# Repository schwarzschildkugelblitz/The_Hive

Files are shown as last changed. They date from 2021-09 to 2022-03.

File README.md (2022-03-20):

# The Hive 
The Following is Team Placeholders Solution to Flipkart's Grid 3.0

## About Grid 3.0
60ccb1a9ee892_d2c__1920-557_01

GRiD is Flipkart’s Flagship Engineering Campus Challenge which provides you the opportunity to apply your technical knowledge and skills, to compete and complete key challenges.

In its third edition, Flipkart GRiD becomes bigger & better, bringing Live Problem Statements from the world of E-Commerce to the brightest minds of India and lets you put your capabilities to the ultimate test.
## Problem  Statement

### Relay race - 4 Robots

1. Each robot has a package on top
2. Start positions are S1, S2, S3 & S4
3. Bot from S1 is expected to go to D1, Bot from S2 is expected to go to D2 and so on...
4. On start - Bot in the S1 location is expected to go to D1
5. On reaching D1 it should drop the item beyond the wall
6. Once the bot comes back to S1 (Completely inside S1 square), only then Bot from S2 can start
7. Race is over when S4 robot comes back to its square after dropping the parcel
No touching of the robots hardware/software is allowed once the race starts - Completely autonomous robots
Overall Arena size is 5 x 10ft

● Each block is 6x6in

● The grid is 1 cm tape / marking

● The brown line next to D1, D2, D3 & D4 is a 1-inch height wall

### Judging Criteria for Round I

Top 100 teams to finish the relay race (shortest time) - make it to Round II

### Deliverables for Round I
1. Pictures of Robots
2. Time taken to complete the relay race
3. Uninterrupted Video of the Relay Race - with Timer overlayed to indicate start and end of race - This
can be shot with a handheld or phone camera
4. Uninterrupted Video of Live Image Processing - with Timer overlayed to show how robots are being
tracked in real-time

## About The Team 
Untitled design

The Team consisted of the following members 
1. Harshit Batra 
2. Tanmay Vadhera
3. Mudit Aggarwal
4. Rohan Deswal
5. Drishti Adlakha 
6. Arjun Narula 
7. Harshit Kapoor
8. Mukul Gupta 
9. Vikas Poddar 
10. Soham

## Achitectrue
architecure drawio (6)

### Queen Tracking System 
### Transmission System
### Worker bee 
WhatsApp Image 2021-09-06 at 4 18 25 PM

## Mechanical

## Electronics 
### Power system 
the worker bee is power by powerfull 7.2 V 2500 mah li-ion Battery

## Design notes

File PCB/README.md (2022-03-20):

# PCB for Bot 

## Iteration 1 

Designed By Team Placeholders and Manufactured By PCB Powers 

### Dimensions

### Parts 

1. Arduino nano 
2. L293D
3. Power circuit 
4. NRF24 

### Funionality 

1. Driving bot's N20 Motor 
2. Driving bot's Servo Motor  
3. Receiving Data from Central Tracking system 

### Schmatic Diagram 
151336828-df838c24-ffac-4909-9ef3-fa408727c776

### 3D view 
pcb_flip

## Iteration 2

Designed By Team Placeholders and Manufactured at CEDT lab,NSUT

### What's new 

1. Added boost cicuit 
2. Changed dimensions 

### Parts 

1. Arduino nano 
2. L293D
3. Power circuit 
4. NRF24 

### Funionality 
1. Driving bot's N20 Motor 
2. Driving bot's Servo Motor  
3. Receiving Data from Central Tracking system 

### Schmatic Diagram 
pcb_flip (1)

### 3D view 
pcb_flip

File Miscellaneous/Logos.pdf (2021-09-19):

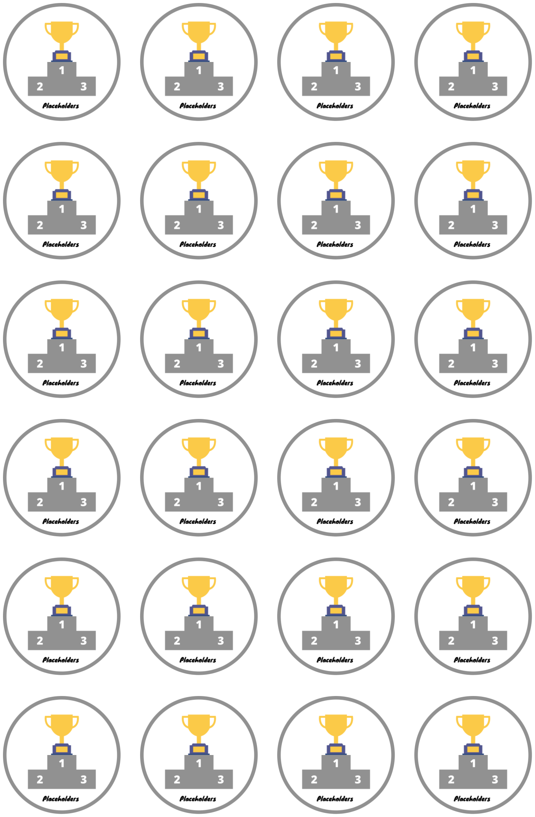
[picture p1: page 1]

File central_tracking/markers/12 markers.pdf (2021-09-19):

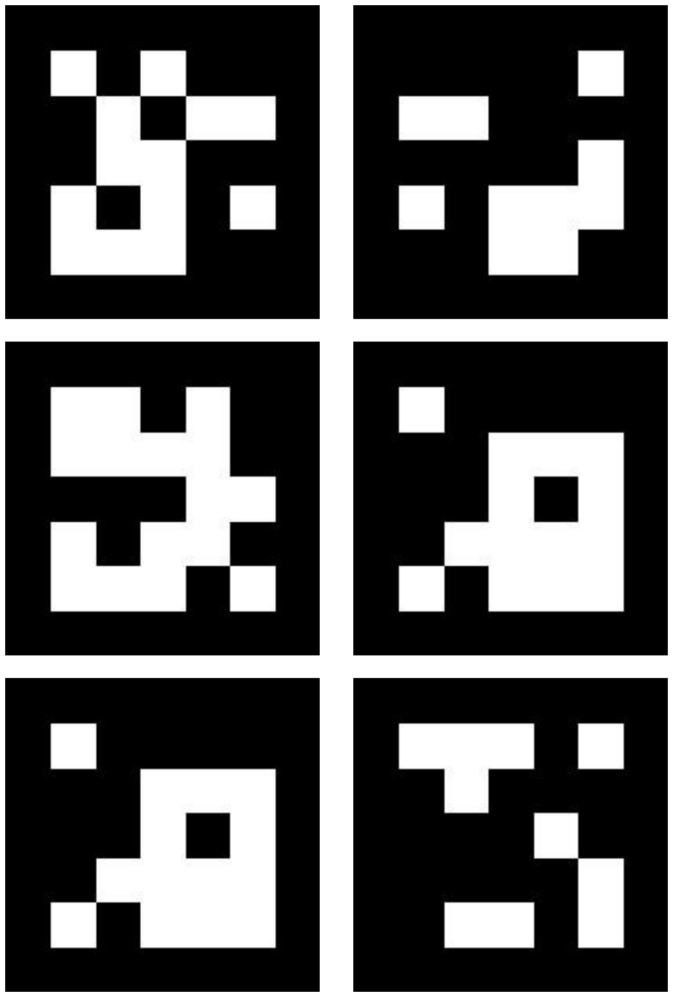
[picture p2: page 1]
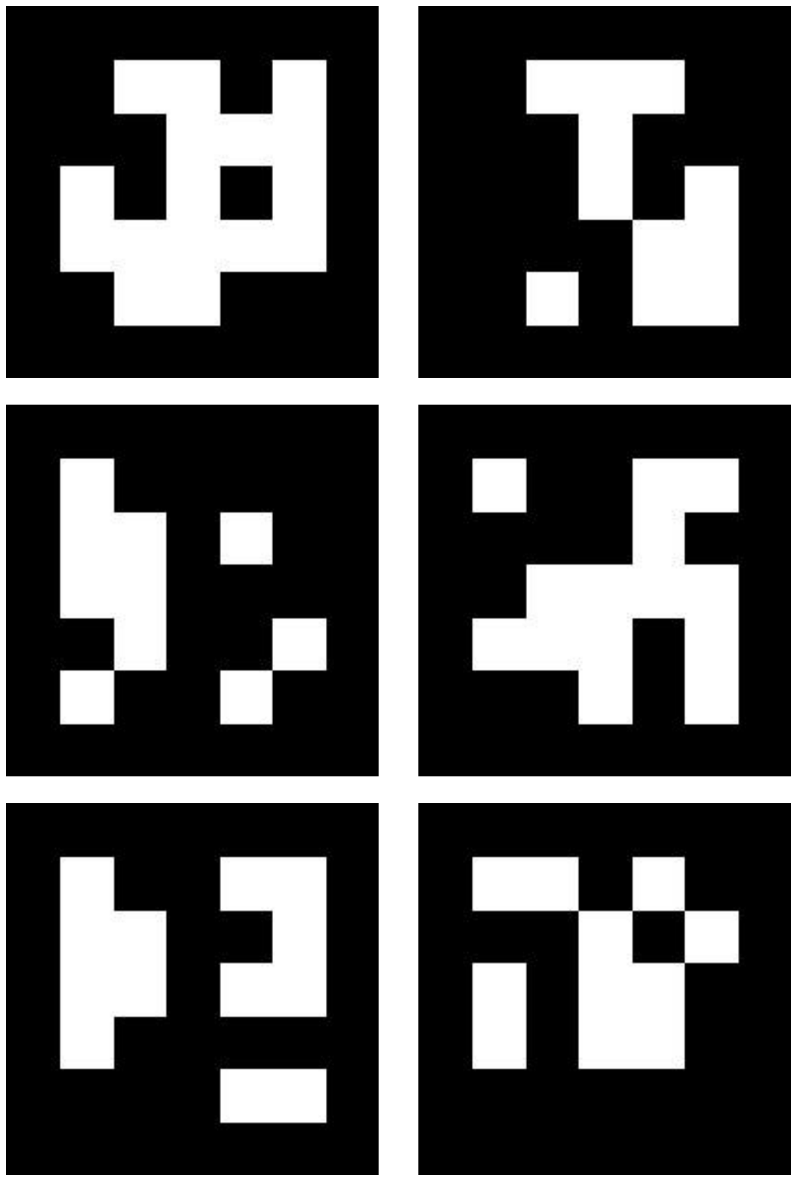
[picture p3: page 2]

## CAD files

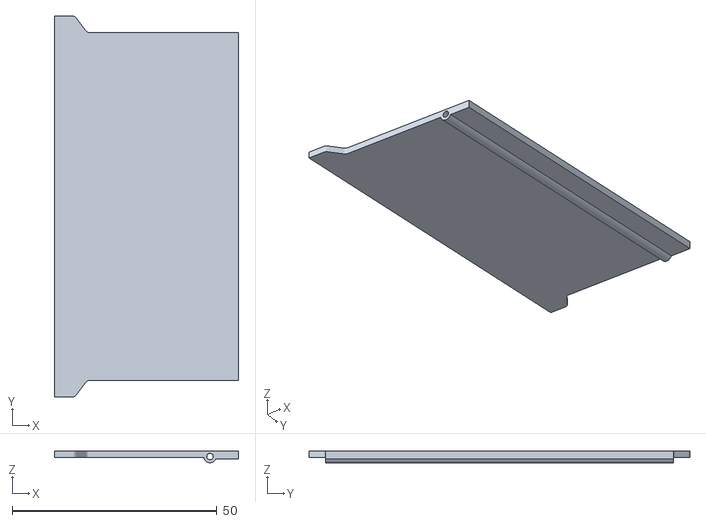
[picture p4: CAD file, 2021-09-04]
CAD_Model/flipper_plate_send.stl
45.0 x 93.0 x 2.84

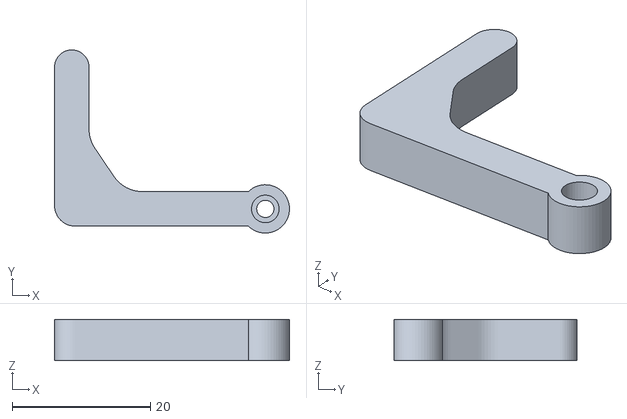
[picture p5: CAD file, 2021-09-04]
CAD_Model/L arm fin.stl
34.0 x 26.5 x 6.00

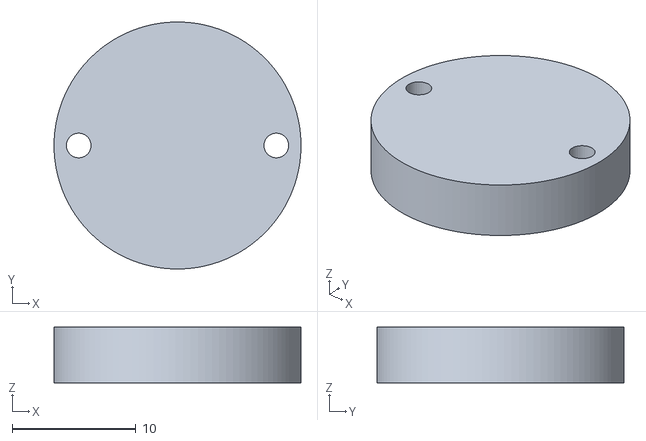
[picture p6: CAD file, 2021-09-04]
CAD_Model/caster spacer v1.stl
20.0 x 20.0 x 4.50

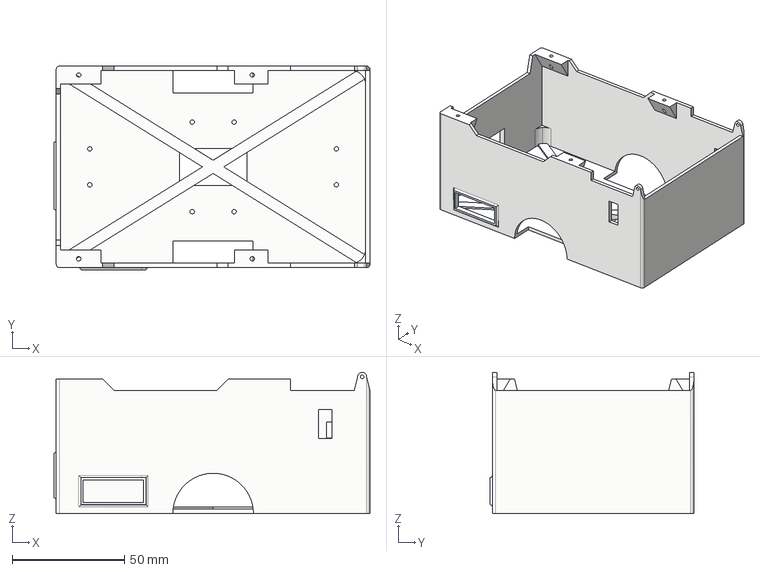
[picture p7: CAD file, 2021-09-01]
CAD_Model/ROBOT_W_changes v3.step
141.0 x 91.0 x 63.0 mm

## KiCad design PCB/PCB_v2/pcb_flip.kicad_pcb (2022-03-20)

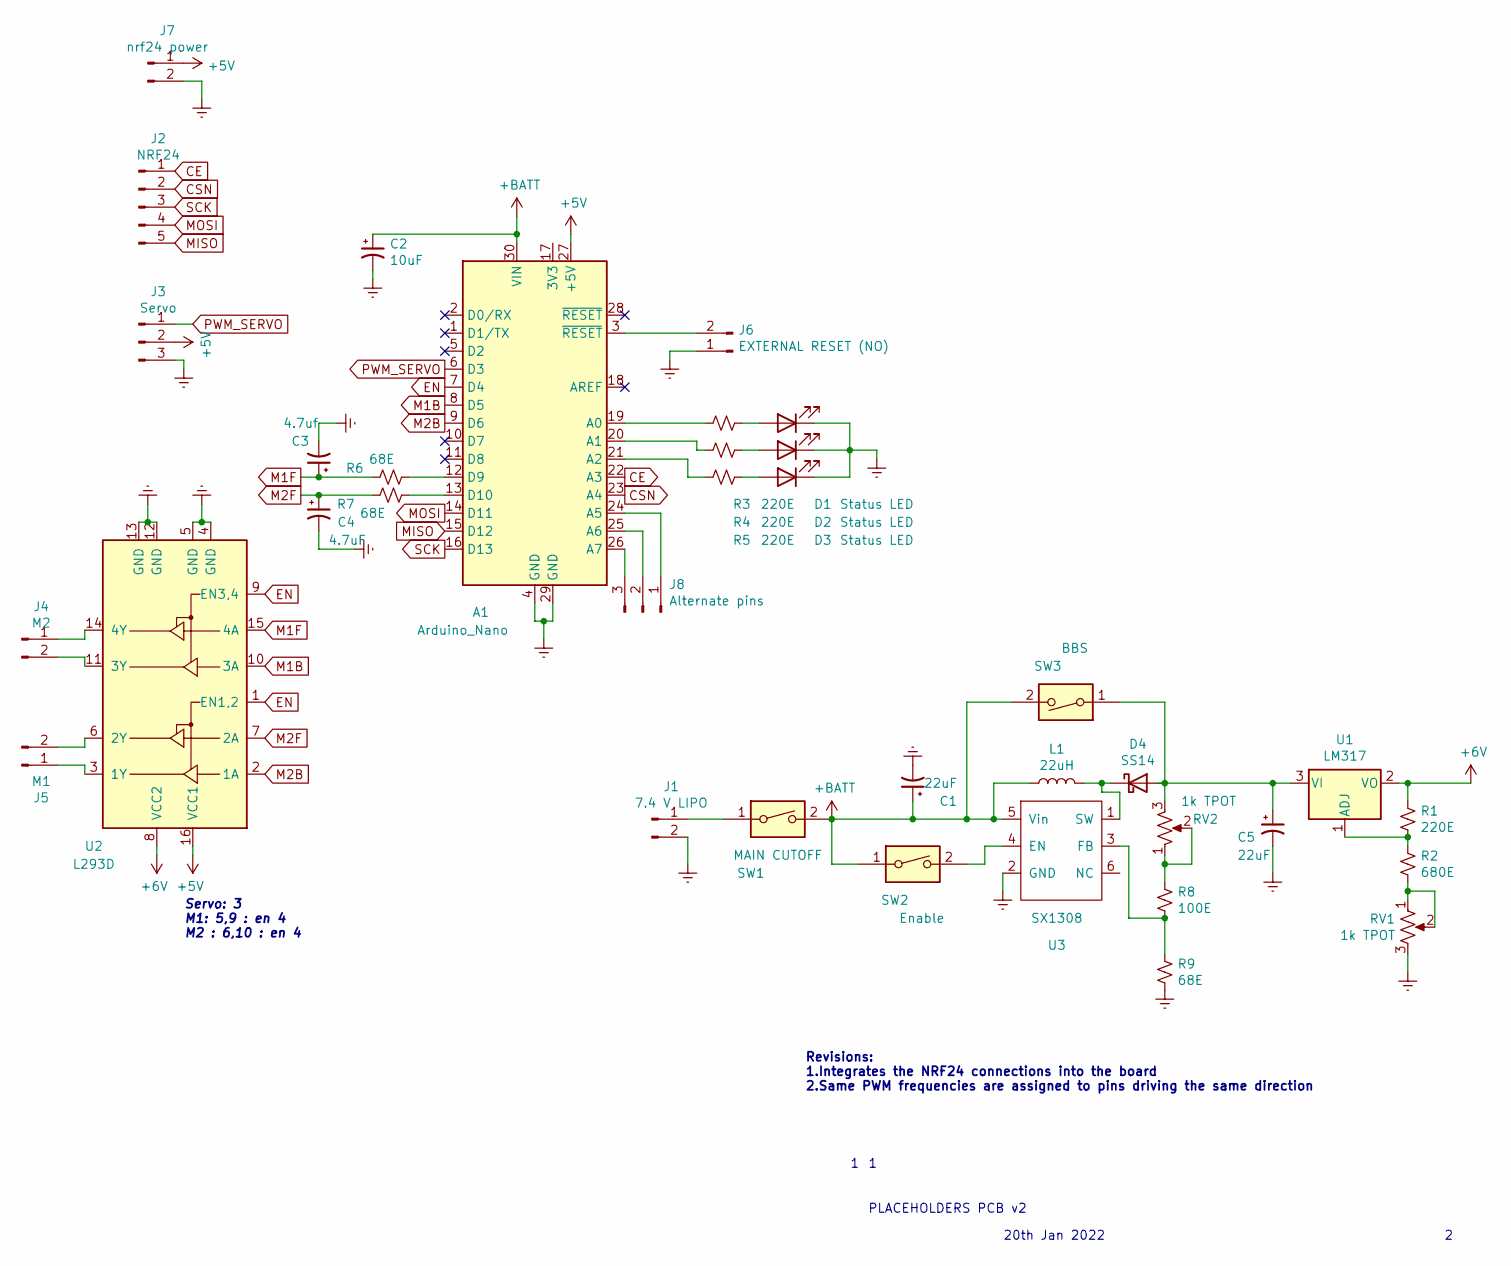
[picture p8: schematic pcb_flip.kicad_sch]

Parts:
A1: Arduino_Nano
C1, C5: 22uF; C_1206_3216Metric_Pad1.33x1.80mm_HandSolder
C2: 10uF; CP_EIA-3528-12_Kemet-T_Pad1.50x2.35mm_HandSolder
C3: 4.7uf; CP_EIA-3528-12_Kemet-T_Pad1.50x2.35mm_HandSolder
C4: 4.7uF; CP_EIA-3528-12_Kemet-T_Pad1.50x2.35mm_HandSolder
D1, D2, D3: Status LED; LED_D5.0mm_IRGrey
D4: SS14; D_1210_3225Metric_Pad1.42x2.65mm_HandSolder
J1: 7.4 V LIPO; JST_XH_B2B-XH-A_1x02_P2.50mm_Vertical
J2: NRF24; PinHeader_1x05_P2.54mm_Vertical
J3: Servo; PinHeader_1x03_P2.54mm_Vertical
J4: M2; TerminalBlock_Phoenix_MKDS-1,5-2_1x02_P5.00mm_Horizontal
J5: M1; TerminalBlock_Phoenix_MKDS-1,5-2_1x02_P5.00mm_Horizontal
J6: EXTERNAL RESET (NO); PinHeader_1x02_P2.54mm_Vertical
J7: nrf24 power; PinHeader_1x02_P2.54mm_Vertical
J8: Alternate pins; PinHeader_1x03_P2.54mm_Vertical
L1: 22uH; L_Radial_D6.0mm_P4.00mm
R1, R3, R4, R5: 220E; R_0805_2012Metric_Pad1.20x1.40mm_HandSolder
R2: 680E; R_0805_2012Metric_Pad1.20x1.40mm_HandSolder
R6, R7: 68E; R_0805_2012Metric_Pad1.20x1.40mm_HandSolder
R8: 100E; R_0805_2012Metric_Pad1.20x1.40mm_HandSolder
R9: 68E; C_0805_2012Metric_Pad1.18x1.45mm_HandSolder
RV1, RV2: 1k TPOT; Potentiometer_Bourns_3296W_Vertical
SW1: MAIN CUTOFF; JST_XH_B2B-XH-A_1x02_P2.50mm_Vertical
SW2: Enable; SolderJumper-2_P1.3mm_Open_TrianglePad1.0x1.5mm
SW3: BBS; SolderJumper-2_P1.3mm_Open_TrianglePad1.0x1.5mm
U1: LM317; TO-220-3_Vertical
U2: L293D; DIP-16_W7.62mm_Socket
U3: SX1308; SOT-23-6_Handsoldering

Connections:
+5V: A1.27 (+5V), J3.2, J7.1, U2.16 (VCC1); also elsewhere on the board
+6V: R1.1, U1.2 (VO), U2.8 (VCC2)
+BATT: A1.30 (VIN), C1.1, C2.1, L1.1, SW1.2, SW2.1, SW3.2, U3.5 (Vin)
CE: A1.22 (A3), J2.1; also elsewhere on the board
CSN: A1.23 (A4), J2.2; also elsewhere on the board
EN: A1.7 (D4), U2.1 (EN1,2), U2.9 (EN3,4)
Earth: A1.4 (GND), A1.29 (GND), C1.2, C2.2, C3.2, C4.2, C5.2, D1.1 (K), D2.1 (K), D3.1 (K), J1.2, J3.3, J6.1, J7.2, R9.2, RV1.3, U2.4 (GND), U2.5 (GND), U2.12 (GND), U2.13 (GND), U3.2 (GND); also elsewhere on the board
M1B: A1.8 (D5), U2.10 (3A)
M1F: C3.1, R6.2, U2.15 (4A)
M2B: A1.9 (D6), U2.2 (1A)
M2F: C4.1, R7.2, U2.7 (2A)
MISO: A1.15 (D12), J2.5; also elsewhere on the board
MOSI: A1.14 (D11), J2.4; also elsewhere on the board
unnamed: A1.3 (~RESET), J6.2
unnamed: A1.12 (D9), R6.1
unnamed: A1.13 (D10), R7.1
unnamed: A1.19 (A0), R3.2
unnamed: A1.20 (A1), R4.2
unnamed: A1.21 (A2), R5.2
unnamed: A1.24 (A5), J8.1
unnamed: A1.25 (A6), J8.2
unnamed: A1.26 (A7), J8.3
unnamed 22: C5.1, D4.2 (A), RV2.3, SW3.1, U1.3 (VI); also elsewhere on the board
unnamed: D1.2 (A), R3.1
unnamed: D2.2 (A), R4.1
unnamed: D3.2 (A), R5.1
unnamed 26: D4.1 (K), L1.2, U3.1 (SW); also elsewhere on the board
unnamed: J1.1, SW1.1
unnamed: J4.1, U2.14 (4Y)
unnamed: J4.2, U2.11 (3Y)
unnamed: J5.1, U2.3 (1Y)
unnamed: J5.2, U2.6 (2Y)
unnamed: R1.2, R2.1, U1.1 (ADJ)
unnamed: R2.2, RV1.1, RV1.2
unnamed: R8.1, RV2.1, RV2.2
unnamed: R8.2, R9.1, U3.3 (FB)
unnamed: SW2.2, U3.4 (EN)
PWM_SERVO: A1.6 (D3), J3.1
SCK: A1.16 (D13), J2.3; also elsewhere on the board

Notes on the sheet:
20th Jan 2022
PLACEHOLDERS PCB v2
Servo: 3 M1: 5,9 : en 4 M2 : 6,10 : en 4
Revisions: 1.Integrates the NRF24 connections into the board 2.Same PWM frequencies are assigned to pins driving the same direction

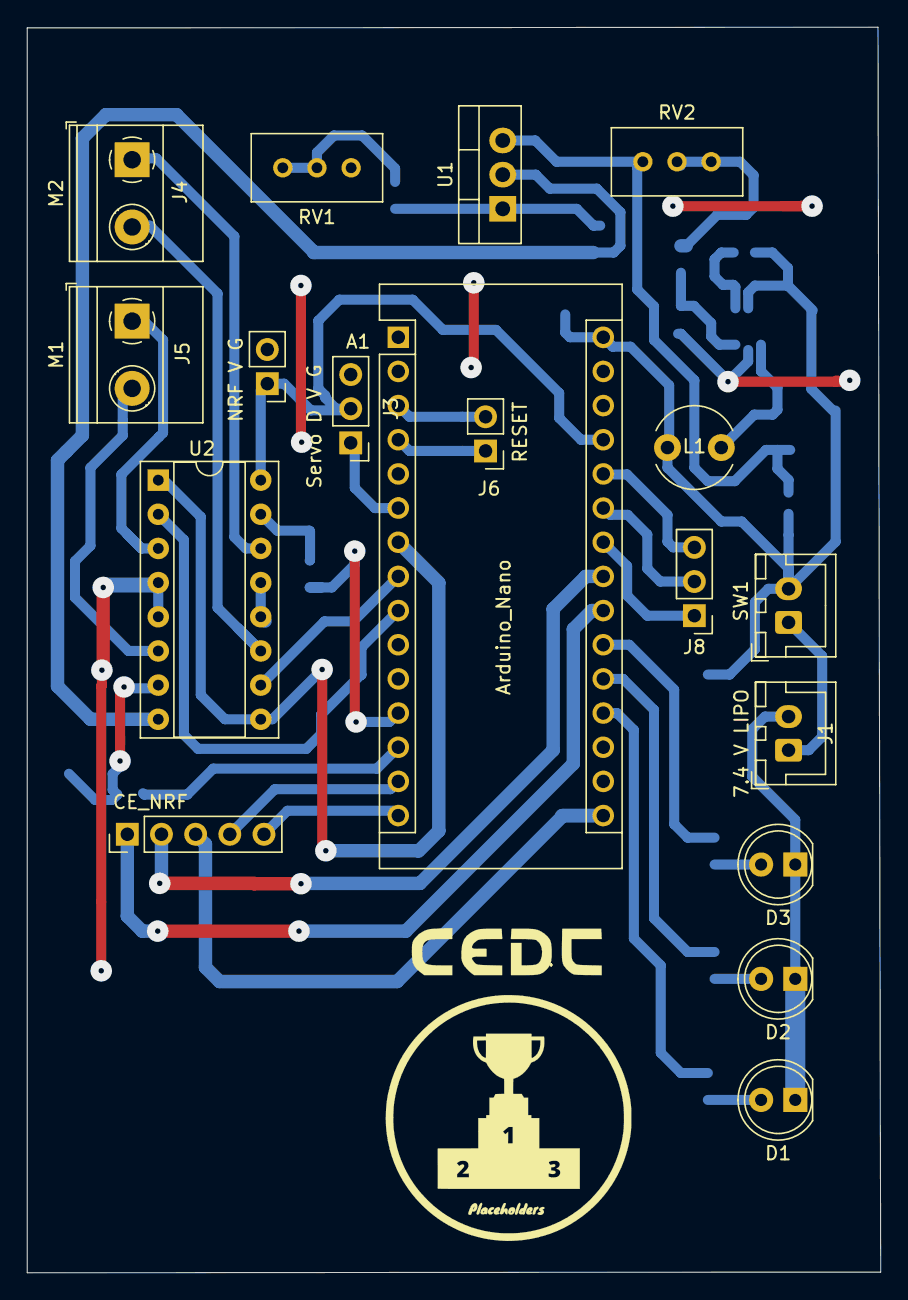
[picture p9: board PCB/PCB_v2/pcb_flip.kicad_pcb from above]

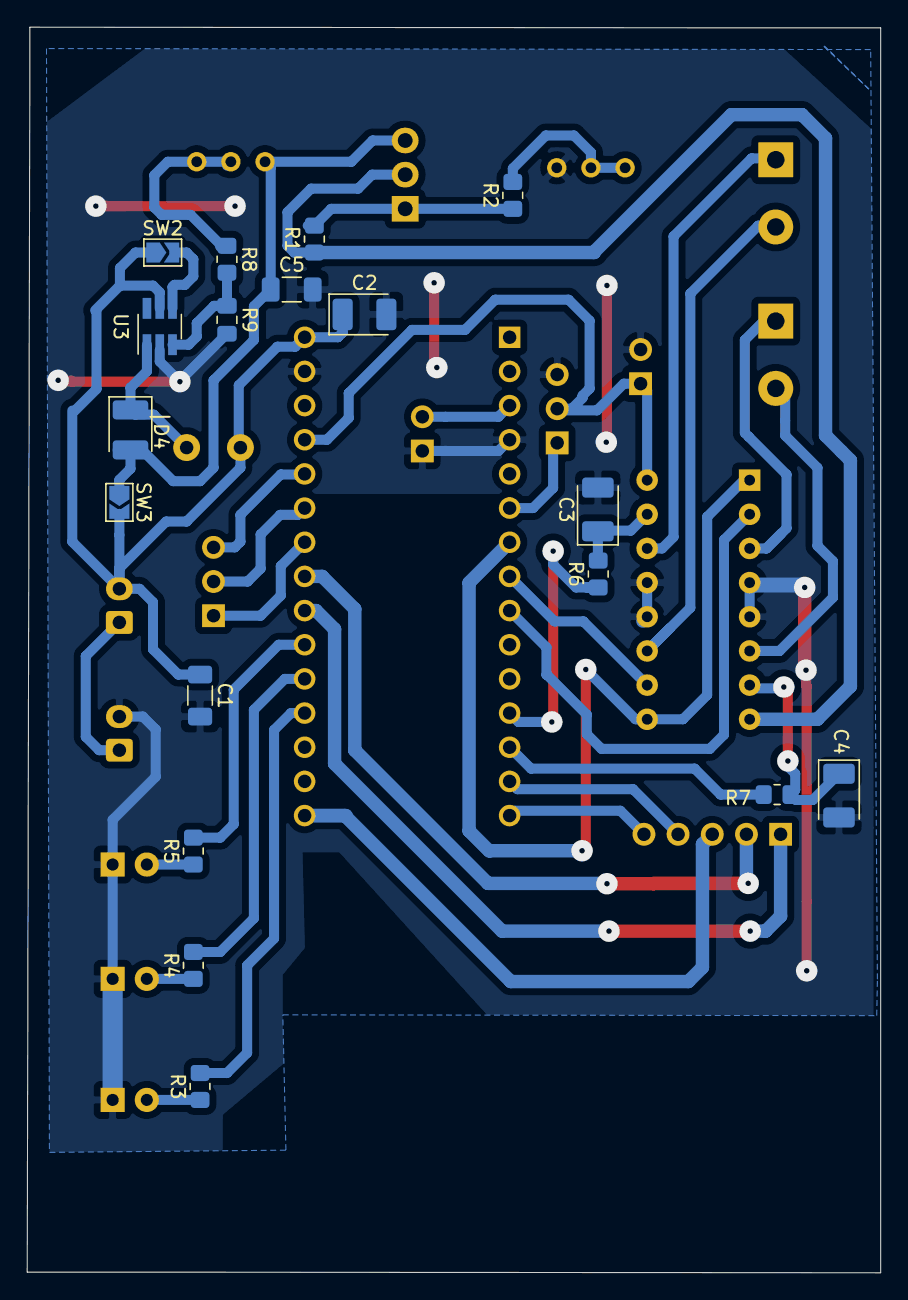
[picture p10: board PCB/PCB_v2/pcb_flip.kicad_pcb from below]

Board: 2 copper layers, 63.4 x 92.6 mm, 38 parts (18 on the bottom side), 39 nets.

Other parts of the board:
CE_NRF: NRF24; PinHeader_1x05_P2.54mm_Vertical
NRF V G: nrf24 power; PinHeader_1x02_P2.54mm_Vertical
RV2-24/01/2022: LOGO; placeholders
T V: LOGO; epp
|D4: SS14; D_1210_3225Metric_Pad1.42x2.65mm_HandSolder

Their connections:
+5V: NRF V G.1; also elsewhere on the board
CE: CE_NRF.1; also elsewhere on the board
CSN: CE_NRF.2; also elsewhere on the board
Earth: NRF V G.2; also elsewhere on the board
MISO: CE_NRF.5; also elsewhere on the board
MOSI: CE_NRF.4; also elsewhere on the board
unnamed 22: |D4.2; also elsewhere on the board
unnamed 26: |D4.1; also elsewhere on the board
SCK: CE_NRF.3; also elsewhere on the board

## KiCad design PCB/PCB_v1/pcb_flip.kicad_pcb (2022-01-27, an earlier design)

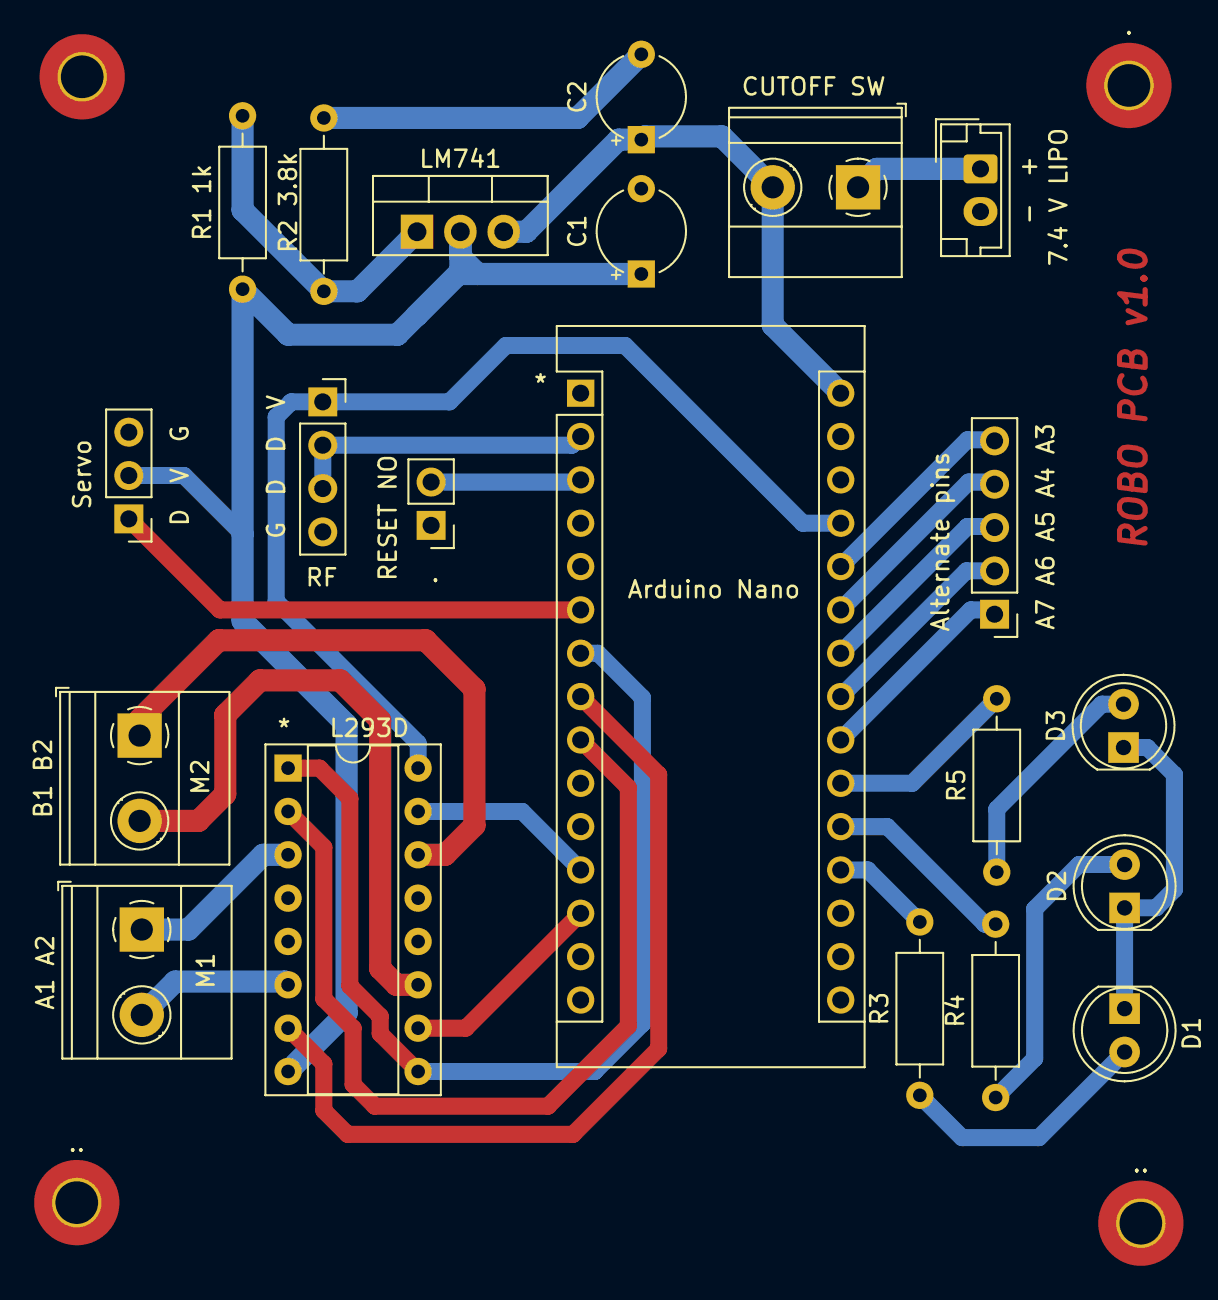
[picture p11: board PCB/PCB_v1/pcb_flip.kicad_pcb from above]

Board: 2 copper layers, 25 parts (0 on the bottom side), 29 nets.

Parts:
 : .; MountingHole_2.5mm_Pad_TopBottom
*   L293D: L293D; DIP-16_W7.62mm_Socket
-  +: 7.4 V LIPO; JST_EH_B2B-EH-A_1x02_P2.50mm_Vertical
., .., ..#2: .; MountingHole_2.5mm_Pad_TopBottom
.#2: RESET NO; PinHeader_1x02_P2.54mm_Vertical
A7 A6 A5 A4 A3: Alternate pins; PinHeader_1x05_P2.54mm_Vertical
Arduino Nano: *; Arduino_Nano
C1, C2: 1uf; CP_Radial_Tantal_D5.0mm_P5.00mm
CUTOFF SW: MAIN CUTOFF; TerminalBlock_Phoenix_MKDS-1,5-2_1x02_P5.00mm_Horizontal
D1, D2, D3: Status LED; LED_D5.0mm
D  V  G: Servo; PinHeader_1x03_P2.54mm_Vertical
LM741: LM317; TO-220-3_Vertical
M1: A1 A2; TerminalBlock_Phoenix_MKDS-1,5-2_1x02_P5.00mm_Horizontal
M2: B1 B2; TerminalBlock_Phoenix_MKDS-1,5-2_1x02_P5.00mm_Horizontal
R1 1k: 1k; R_Axial_DIN0207_L6.3mm_D2.5mm_P10.16mm_Horizontal
R2 3.8k: 3.8k; R_Axial_DIN0207_L6.3mm_D2.5mm_P10.16mm_Horizontal
R3, R4, R5: 220E; R_Axial_DIN0207_L6.3mm_D2.5mm_P10.16mm_Horizontal
RF: G D D V; PinSocket_1x04_P2.54mm_Vertical

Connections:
+5V: * L293D.16, Arduino Nano.27, RF.1
+6V: * L293D.8, C1.1, D V G.2, LM741.2, R1 1k.1
+BATT: Arduino Nano.30, C2.1, CUTOFF SW.2, LM741.3
Earth: * L293D.4, * L293D.5, * L293D.12, * L293D.13, - +.2, .#2.1, Arduino Nano.4, Arduino Nano.29, C1.2, C2.2, D1.1, D2.1, D3.1, D V G.3, R2 3.8k.2, RF.4
unnamed: Arduino Nano.2, RF.2, RF.3
unnamed: .#2.2, Arduino Nano.3
unnamed: Arduino Nano.6, D V G.1
unnamed: * L293D.1, * L293D.9, Arduino Nano.7
unnamed: * L293D.7, Arduino Nano.8
unnamed: * L293D.2, Arduino Nano.9
unnamed: * L293D.15, Arduino Nano.12
unnamed: * L293D.10, Arduino Nano.13
unnamed: Arduino Nano.19, R3.2
unnamed: Arduino Nano.20, R4.2
unnamed: Arduino Nano.21, R5.2
unnamed: A7 A6 A5 A4 A3.1, Arduino Nano.22
unnamed: A7 A6 A5 A4 A3.2, Arduino Nano.23
unnamed: A7 A6 A5 A4 A3.3, Arduino Nano.24
unnamed: A7 A6 A5 A4 A3.4, Arduino Nano.25
unnamed: A7 A6 A5 A4 A3.5, Arduino Nano.26
unnamed: D1.2, R3.1
unnamed: D2.2, R4.1
unnamed: D3.2, R5.1
unnamed: - +.1, CUTOFF SW.1
unnamed: * L293D.14, M2.1
unnamed: * L293D.11, M2.2
unnamed: * L293D.3, M1.1
unnamed: * L293D.6, M1.2
unnamed: LM741.1, R1 1k.2, R2 3.8k.1

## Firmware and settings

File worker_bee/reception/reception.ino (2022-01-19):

/* RECEPTION CODE handles reception , decoding and execution of various commands
given by central tracking system 

written by Tanmay Vadhera
and minor changes made by Mudit Aggarwal, Rohan Deswal and Harshit Batra 


dependies  
    - ServoTimer2.h
    - SPI.h
    - RH_NRF24.h 
*/

#include <ServoTimer2.h>  // the servo library
#include <SPI.h>  // SPI library 
#include <RH_NRF24.h> //NRF library 

#define Worker_bee_Address 1
#define LEFT 95 // speed of left motor
#define RIGHT 106 // speed of right motor
#define tau 0.00016
#define a 0.0017
#define b 0.00000288
#define h 0.00102
#define l 0.00204
RH_NRF24 nrf24 (A4,A3);
ServoTimer2 flipper_servo; 


class motor 
{
  public:
  int pin1,pin2,En;
  motor(int pinA,int pinB,int en=4)
  {
    pin1=pinA;
    pin2=pinB;
    En = en;
    pinMode(pin1,OUTPUT);
    pinMode(pin2,OUTPUT);
    pinMode(en,OUTPUT);
    digitalWrite(En,1);
  }
  void move(int val1,int val2)
  {
    analogWrite(pin1,val1);
    analogWrite(pin2,val2);
  }

  void fd()
  {
//    digitalWrite(pin1,1);
//    digitalWrite(pin2,0);

    analogWrite(pin1,100);
    analogWrite(pin2,0);
  }
  
  void bk()
  {
//    digitalWrite(pin1,0);
//    digitalWrite(pin2,1);

    analogWrite(pin1,0);
    analogWrite(pin2,100);
  }
  
  void stp()
  {
    digitalWrite(pin1,0);
    digitalWrite(pin2,0);
  }

}L(10, 9),R(6,5); // instances


uint8_t add,sign,spd2,misc;
int8_t spd1;

void unpack (uint8_t pack[])
{
  add=0;
  spd2=0;
  misc=0;
  spd1=0;
  uint8_t cnt=0;  

  sign = pack[1];
  
  if (pack[0] !=0){
    spd1 = pack[0]>>2;       
    add = pack[0]&3;
  }
}

void setup() 
{
  pinMode(A0,OUTPUT);
  pinMode(A2,OUTPUT);
  flipper_servo.attach(3);
  flipper_servo.write(1120);
  delay(1000);
  pinMode (10,OUTPUT);
  digitalWrite(10,0);
  Serial.begin(9600);
  
  if (!nrf24.init())
    Serial.println("init failed");
    
  // Defaults after init are 2.402 GHz (channel 2), 2Mbps, 0dBm
  if (!nrf24.setChannel(2))
    Serial.println("setChannel failed");
    
  if (!nrf24.setRF(RH_NRF24::DataRate2Mbps, RH_NRF24::TransmitPower0dBm))
    Serial.println("setRF failed");    
  
  flipper_servo.write(-130);
  delay(1000);  
  flipper_servo.write(1120);

//  R.move(RIGHT+(int)spd1,0);
//  L.move(LEFT-(int)spd1,0);
//  delay(1000);
}

uint8_t len;
unsigned int num_trans = 0;
void loop()
{
//  myservo.write(1130);
  if (nrf24.available())
  {
    //Serial.println("Rohan");
    uint8_t buf[RH_NRF24_MAX_MESSAGE_LEN];
    len = sizeof(buf);
  
    if (nrf24.recv(buf, &len))
    {
        num_trans+=1;
        
//      Serial.print(buf[0]);
//      Serial.print(" ");
//      Serial.print(buf[1]);
        
      unpack(buf);
//
      Serial.print(" -> ");
      Serial.print(add);
      Serial.print(" ");
      Serial.println(spd1);
                 
      if(add == Worker_bee_Address) // do anything only if the address matches
      {
        
        if (num_trans++ >= 5 && num_trans < 10) // blinky blinky
          digitalWrite(A2,1);
         else if (num_trans >= 10) 
          {
            num_trans = 0;
            digitalWrite(A2,0);
          }
          
        if (spd1>=0 && spd1 <= 55)
        {
          spd1 = sign == 1 ? -spd1 : spd1; // sign = 1 indicates that spd1 is negative

//          digitalWrite(A0,HIGH);
//          delay(500);
//          digitalWrite(A0,LOW);
//          delay(500);
          
          R.move(RIGHT + spd1,0);
          L.move(LEFT  - spd1,0);
//          changes made 
//          delay(5); 
//          R.move(RIGHT,0);
//          L.move(LEFT,0);
          
        }
        // mode instances          
        else if(spd1 == 56)  
        {   // left
            L.move(0,200);
            R.move(0,200);
            delay(30);
            L.stp();
            R.stp();
            delay(100);
            L.move(0,150);
            R.move(150,0);
            delay(330);
            L.move(150,0);
            R.move(0,150);
            delay(20);
            L.stp();
            R.stp();
            delay(50);
        }
        else if (spd1 == 57)
        {   // right
            L.move(0,200);
            R.move(0,200);
            delay(30);
            L.stp();
            R.stp();
            delay(100);
            L.move(150,0);
            R.move(0,150);
            delay(370);
            L.move(0,150);
            R.move(150,0);
            delay(20);
            L.stp();
            R.stp();
            delay(50);
        }
        else if (spd1 == 58)
        {   // stop
          L.stp();
          R.stp();
        }
        else if(spd1 == 59){ 
          // right_drop
          L.move(0,200);
          R.move(0,200);
          delay(30);
          L.stp();
          R.stp();
          delay(100);
          L.move(150,0);
          R.move(0,150);
          delay(370);
          L.move(0,150);
          R.move(150,0);
          delay(20);
          L.stp();
          R.stp();
          delay(50);
          
          
          L.move(150,0);
          R.move(150,0);
          delay(300);
          L.stp();
          R.stp();
          delay(100);
          
          flipper_servo.write(-130);
          delay(500);  
          flipper_servo.write(1120);
          delay(100);
      
          L.move(0,150);
          R.move(0,150);
          delay(250);
          L.stp();
          R.stp();
        }
        else if(spd1 == 60)
        // left_drop
        {
          L.move(0,200);
          R.move(0,200);
          delay(30);
          L.stp();
          R.stp();
          delay(100);
          L.move(0,150);
          R.move(150,0);
          delay(300);
          L.move(150,0);
          R.move(0,150);
          delay(20);
          L.stp();
          R.stp();
          delay(50);
          
          
          L.move(150,0);
          R.move(150,0);
          delay(300);
          L.stp();
          R.stp();
          delay(100);
          
          flipper_servo.write(-130);
          delay(500);  
          flipper_servo.write(1120);
          delay(100);
      
          L.move(0,150);
          R.move(0,150);
          delay(250);
          L.stp();
          R.stp();
        }
        else if (spd1 == 61)
        // drop
        {
          L.move(150,0);
          R.move(150,0);
          delay(300);
          L.stp();
          R.stp();
          delay(100);
          
          flipper_servo.write(-130);
          delay(500);  
          flipper_servo.write(1120);
          delay(100);
      
          L.move(0,150);
          R.move(0,150);
          delay(250);
          L.stp();
          R.stp();
        }
        else if (spd1 == 62)
        //180
        {
          //  delay(100);
          //  L.move(0,150);
          //  R.move(0,150);
          //  
          //  delay(600);
            L.move(150,0);
            R.move(0,160);
            delay(640);
            L.move(0,200);
            R.move(200,0);
            delay(30);
            L.stp();
            R.stp();
          
          //  delay(20);
          //  L.move(0,150);
          //  R.move(0,150);
          //  delay(550);
          //  L.stp();
          //  R.stp();
        }
        else if (spd1 == 63);
        //null  
      }
    }
  }
}

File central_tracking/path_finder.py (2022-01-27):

""" this code was written by Rohan Deswal

as part of hive round 2 """
import numpy as np
import pygame
from math import atan2, degrees
from path_gen import gen_path

locations = {
    'Mumbai': 1,
    'Delhi': 2,
    'Kolkata': 3,
    'Chennai': 4,
    'Bengaluru': 5,
    'Hyderabad': 6,
    'Pune': 7,
    'Ahmedabad': 8,
    'Jaipur': 9
}

locations_coords = {
    '1': (4, 0),
    '2': (9, 0),

    'Mumbai': (2, 3),
    'Delhi': (2, 7),
    'Kolkata': (2, 11),
    'Chennai': (6, 3),
    'Bengaluru': (6, 7),
    'Hyderabad': (6, 11),
    'Pune': (10, 3),
    'Ahmedabad': (10, 7),
    'Jaipur': (10, 11)
}


colors = {
    -3: (77, 53, 51), # Custom Blocks
    -2: (158, 0, 69),  # Node to Visit
    -1: (0, 0, 0),  # Blocked Cell
    0: (255, 255, 255),  # Empty Cell
    1: (171, 169, 166),  # Mumbai
    2: (25, 98, 224),  # Delhi
    3: (252, 223, 76),  # Kolkata
    4: (252, 158, 76),  # Chennai
    5: (243, 116, 247),  # Bengaluru
    6: (242, 19, 49),  # Hyderabad
    7: (51, 135, 68),  # Pune
    8: (145, 81, 35),  # Ahmedabad
    9: (119, 67, 191)  # Jaipur
}
arena = [[-1, 0, 0, 0, 0, 0, 0, 0, 0, 0, 0, 0, 0, 0, 0],
         [-1, 0, 0, 0, 0, 0, 0, 0, 0, 0, 0, 0, 0, 0, 0],
         [-1, 0, 0, 1, 1, 0, 0, 2, 2, 0, 0, 3, 3, 0, 0],
         [-1, 0, 0, 1, 1, 0, 0, 2, 2, 0, 0, 3, 3, 0, 0],
         [ 0, 0, 0, 0, 0, 0, 0, 0, 0, 0, 0, 0, 0, 0, 0],
         [-1, 0, 0, 0, 0, 0, 0, 0, 0, 0, 0, 0, 0, 0, 0],
         [-1, 0, 0, 4, 4, 0, 0, 5, 5, 0, 0, 6, 6, 0, 0],
         [-1, 0, 0, 4, 4, 0, 0, 5, 5, 0, 0, 6, 6, 0, 0],
         [-1, 0, 0, 0, 0, 0, 0, 0, 0, 0, 0, 0, 0, 0, 0],
         [ 0, 0, 0, 0, 0, 0, 0, 0, 0, 0, 0, 0, 0, 0, 0],
         [-1, 0, 0, 7, 7, 0, 0, 8, 8, 0, 0, 9, 9, 0, 0],
         [-1, 0, 0, 7, 7, 0, 0, 8, 8, 0, 0, 9, 9, 0, 0],
         [-1, 0, 0, 0, 0, 0, 0, 0, 0, 0, 0, 0, 0, 0, 0],
         [-1, 0, 0, 0, 0, 0, 0, 0, 0, 0, 0, 0, 0, 0, 0]]


def get_locations_coords(location_tag, suffix_val):
    if location_tag == '1' or location_tag == '2':
        return locations_coords[location_tag]

    row, col = locations_coords[location_tag]
    
    offsets = [-1,-1,0,1,2,2,1,0]

    return row + offsets[suffix_val-1], col + offsets[-suffix_val]


def get_bot_angle(bot_top_left, bot_bottom_left):
    return atan2(bot_top_left[1] - bot_bottom_left[1], bot_top_left[0] - bot_bottom_left[0])


def get_align_command(bot_vector, path_vectors):
    angle_threshold = 45

    direction = [path_vectors[1][0] - path_vectors[0][0], path_vectors[1][1] - path_vectors[0][1]]

    angle = atan2(bot_vector[0] * direction[1] - bot_vector[1] * direction[0],
                  bot_vector[0] * direction[0] + bot_vector[1] * direction[1])

    angle = degrees(angle)

    if abs(angle - 90) < angle_threshold:
        return ['left']
    elif abs(angle + 90) < angle_threshold:
        return ['right']
    elif not abs(angle) <= angle_threshold:
        return ['180']
    return ['stop']


def get_turns_only(path):
    out = [path[0]]
    i = 0
    j = 1
    while i < len(path) - 1:
        while j < len(path):
            if path[i][0] != path[j][0] and path[i][1] != path[j][1]:
                out.append(path[j - 1])
                break
            j += 1
        i = j - 1
        j = i + 1

    return out + [path[-1]]


def get_drop_align(bot_vectors, path_vectors):
    # print('BV:',bot_vectors)
    a = (bot_vectors[1][0] - bot_vectors[0][0], bot_vectors[1][1] - bot_vectors[0][1])
    b = (path_vectors[1][0] - path_vectors[0][0], path_vectors[1][1] - path_vectors[0][1])

    angle = atan2(a[0] * b[1] - a[1] * b[0], a[0] * b[0] + a[1] * b[1])

    if angle > 0:
        return ['left_drop']
    elif angle < 0:
        return ['right_drop']
    return ['drop']


def get_turns(turns_only_path):
    turns = []

    for i in range(1, len(turns_only_path) - 1):

        a = (turns_only_path[i][0] - turns_only_path[i - 1][0], turns_only_path[i][1] - turns_only_path[i - 1][1])
        b = (turns_only_path[i + 1][0] - turns_only_path[i][0], turns_only_path[i + 1][1] - turns_only_path[i][1])

        angle = atan2(a[0] * b[1] - a[1] * b[0], a[0] * b[0] + a[1] * b[1])
        # print(angle)
        if angle > 0:
            turns.append('left')
        else:
            turns.append('right')
    return turns


def get_distance(path):
    dist = 0
    for i in range(len(path) - 1):
        y1, x1 = path[i]
        y2, x2 = path[i + 1]

        dist += ((y2 - y1) ** 2 + (x2 - x1) ** 2) ** 0.5
    return dist


class PathFinder:
    def __init__(self, w, h):
        self.width = w
        self.height = h
        self.rows = 14
        self.cols = 15
        self.scale = w // self.cols
        self.points_to_visit = []
        self.calculate_path = False
        self.calculate_button_coord = (3 * self.scale, self.rows * self.scale)
        self.reset_button_coord = (11 * self.scale, self.rows * self.scale)
        self.path = []
        self.new_blocks = []
        self.line_path = []

    def reset(self):
        for point in self.points_to_visit:
            arena[point[0]][point[1]] = 0
        for point in self.new_blocks:
            arena[point[0]][point[1]] = 0
        self.__init__(self.width,self.height)


    def draw_path(self):
        pygame.init()

        game_display = pygame.display.set_mode((self.width, self.height + self.scale))
        pygame.display.set_caption('PathFinder Visualisation')

        clock = pygame.time.Clock()
        crashed = False
        while not crashed:
            for event in pygame.event.get():
                if event.type == pygame.QUIT:
                    crashed = True
                elif event.type == pygame.KEYDOWN:
                    if event.key == pygame.K_ESCAPE:
                        crashed = True

                # Press Events
                elif event.type == pygame.MOUSEBUTTONDOWN:
                    if event.button == 3:  # Set Nodes to Visit In Order
                        if not self.calculate_path:
                            x, y = pygame.mouse.get_pos()
                            if y // self.scale < self.rows and x // self.scale < self.cols and \
                                    arena[y // self.scale][x // self.scale] == 0:
                                self.points_to_visit.append([y // self.scale, x // self.scale])
                    if event.button == 1:  # Find Path Button or Reset
                        x, y = pygame.mouse.get_pos()
                        if self.calculate_button_coord[0] <= x <= self.calculate_button_coord[0] + self.scale and \
                                self.calculate_button_coord[1] <= y <= self.calculate_button_coord[1] + self.scale:
                            self.calculate_path = True
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

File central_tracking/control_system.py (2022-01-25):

import cv2
import numpy as np
import time

from bot import Bot
from fetch_job import job_generator
from path_finder import PathFinder, locations, colors

robots = [4, 5, 6, 7]  # marker labels of robots

# proximity threshold to the target coordinate of path
threshold = 40


def special_command(bot_command):
    """
    Special commands called after each step, the function looks up the command
    and returns it
    commands:
        left -> 90° anti-clockwise rotation
        right -> 90° clockwise rotation
        stop -> Halt the robot
        drop -> Drop the package and 180° turn
    """

    commands = {'left': 56, 'right': 57, 'stop': 58, 'right_drop': 59, 'left_drop': 60, 'drop': 61, '180': 62}  # speed
    delay = {'left': 0.5, 'right': 0.5, 'stop': 0.5, 'right_drop': 2, 'left_drop': 2, 'drop': 1, '180': 1}  # delay

    return commands[bot_command], delay[bot_command]


def is_equal(arr_a, arr_b):
    """
    Function to compare equality of two arrays
    containing vectors
    """
    if len(arr_a) != len(arr_b):
        return False
    else:
        for i in range(len(arr_a)):
            a = arr_a[i]
            b = arr_b[i]

            if a[0] != b[0] or a[1] != b[1]:
                return False
        return True


class ControlSystem:
    """
    Manages all the commands to every robot
    """

    def __init__(self, width, height):
        self.width = width
        self.height = height

        self.bots = [Bot(i, robots[i]) for i in range(4)]

        self.job = job_generator()
        self.path_finder = PathFinder(self.width, self.height)

        # PID (feedback) system variables
        self.filter_state = np.zeros(4, dtype=np.float32)
        self.integrator_state = np.zeros(4, dtype=np.float32)
        self.Kp = 0.0071 / 40
        self.Ki = 3.1364 / 40
        self.Kd = 0.14 / 40
        self.N = 4.5
        self.priority = [0, 1, 2, 3]

        self.signals = []
        self.bot_group = 0

    def command(self, detected_markers, detected_labels):
        """
        Generates and returns commands for the robots.
        Robots need to reach the next target in their respective paths
        to account for any deviation, a correction system (based on PID)
        is used which constantly corrects for the angle of robot with the current path

        parameters:
            markers -> np.float32 array storing coordinates of all points of markers of all robots
            labels -> aruco marker label of the robot with detected coordinates respectively

        returns:
            a byte string of uint8 numbers denoting the offset speed and sign of direction of robot
            e.g. "32 -1\n"
            here 32 is the speed offset for left and right motors of robot which helps
            it to turn and correct its angle

            -1 means the robot needs to turn clockwise for correction
            1 means the robot needs to turn anti-clockwise for correction
        """

        self.signals = []
        self.priority = []

        for bot in self.bots:

            # iterate over all robots and store their coordinates
            if detected_labels is not None and bot.marker_id in detected_labels:
                bot.marker = detected_markers[list(detected_labels).index(bot.marker_id)][0]

            bot.set_center()

            if time.time() - bot.command_start < bot.command_delay:
                continue

            if bot.idle:
                job = next(self.job)
                bot.payload = job[0]
                bot.target, bot.next_target = job[1], job[2]
                if bot.id == 0: # or bot.id == 1:
                    bot.path, bot.commands = self.path_finder.get_path(bot.target, bot.coords,
                                                                       bot.marker[0], bot.marker[3])
                    bot.path_color = colors[locations[job[2]]]
                    if len(bot.path) > 0: # Boom Rohan
                        print(bot.id, bot.path, bot.commands, bot.target, bot.next_target)
                bot.idle = False
                
                # if bot.id == 1:
                #     print(bot.path, bot.commands, bot.target, bot.next_target)

            if bot.next_target is not None and bot.path is not None:
                self.priority.append(bot.id)

            if bot.transition:
                bot.path, bot.commands = self.path_finder.get_path(bot.target, bot.coords,
                                                                   bot.marker[0], bot.marker[3])
                bot.transition = False
                if bot.path is not None:
                    print(bot.id, bot.path, bot.commands, bot.target, bot.next_target)

            # bot.blocked = False
            bot.set_angle()

        self.priority.sort(key=lambda bot_id: self.path_finder.get_induction_distance(self.bots[bot_id].path))
        for bot in self.bots:
            if bot.id not in self.priority:
                self.priority.append(bot.id)

        self.priority = self.priority[::-1]

        for bot in self.bots[self.bot_group:self.bot_group + 1]:

            if time.time() - bot.command_start < bot.command_delay:
                continue

            if bot.target_dist() < threshold or bot.step >= len(bot.commands):
                try:
                    bot.old_target = bot.path[bot.step]
                except IndexError:
                    bot.old_target = bot.path[-1]

                bot.command_start = time.time()
                speed, bot.command_delay = special_command(bot.get_command())
            else:
                speed = self.pid(bot)

            if bot.old_target_dist() < threshold:
                self.integrator_state[bot.id] = 0.0
                self.filter_state[bot.id] = 0.0

            for high_priority_bot_id in self.priority[self.priority.index(bot.id):]:
                if high_priority_bot_id != bot.id:
                    if bot.check_collision(self.bots[high_priority_bot_id]):
                        # print(f"{bot.id} is colliding with {high_priority_bot_id} at " +
                        #       f"{self.bots[high_priority_bot_id].coords}")
                        # print(self.bots[high_priority_bot_id].coords)
                        
                        # if bot.recalculate is None:
                        #     bot.blocked = True
                        #     bot.recalculate = time.time()
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

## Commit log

2021-06-26 Create pcb_design
2021-06-26 Add files via upload
    Main circuit board for the robot.
2021-06-28 Implemented tracking markers and added perspective correction
    [make_markers.py, marker_detection.py]
2021-06-29 fixed some array parsing errors
    [marker_detection.py]
2021-09-04 Rename main_body/ROBOT_W_changes v3.step to mechanical/ ROBOT_W_changes v3.step
    [ROBOT_W_changes v3.step]
2021-09-04 Rename mechanical/ROBOT_W_changes v3.step to CAD_Model/ROBOT_W_changes v3.step
    [ROBOT_W_changes v3.step]
2021-09-07 added communication detalis
    0-3 bits address
    case 1 - angle(in degrees) 2 decimal precision
    - distance (in cm ) 2 decimal places
    case 2 - 0 stop 1 right 2 left 3 drop 4 slow drive
2021-09-19 PID system added, initial system altered, code is undocumented
2021-09-28 Using only single camera, PID system updated, code refactored
2021-09-29 Final working code for round 1 tuned PID, changes in path calculation
2022-01-02 round 2 code,m PID adjusted
2022-01-04 Adjusted PID Values with True Divide Error Fix
    [control_system.py]
2022-01-04 Updated Value Adjustments for difference in motor speeds
2022-01-04 Added Code for KIll Switch
2022-01-04 Stop Button Integration in round_2 branch
2022-01-05 round 2 collision detection and multiprocessing
    [bot.py, control_system.py, main_loop.py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]
2022-01-07 pathfinding ind-1 completed and ind-2 to be checked 😊
2022-01-08 Reverted Back to Pre Drop AligningRevert "updated astar.py"
    This reverts commit cbd10ec3fde4a2e8de5573e28950942e1b3babec.
    [astar.py]
2022-01-17 added error in astar
    [astar.py, path_finder.py]
2022-01-18 Alternate Path Gen Bug Fixxes
    [path_finder.py, path_gen.py]
2022-01-18 almost ready for testing round 2 multiple (fixed)
    [control_system.py]
2022-01-27 minor changes
    [pcb_flip-B_Cu.gbr, pcb_flip-B_Mask.gbr, pcb_flip-B_Paste.gbr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]
